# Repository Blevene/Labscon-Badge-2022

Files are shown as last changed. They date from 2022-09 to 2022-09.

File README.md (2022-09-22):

# Labscon-Badge-2022

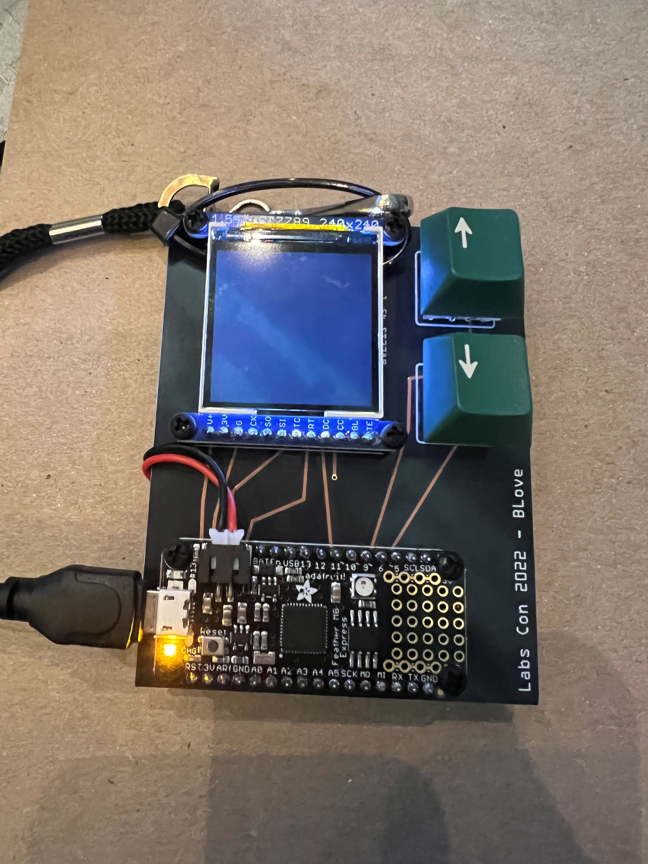
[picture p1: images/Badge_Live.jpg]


## Must use INDEXED bmp files to render on the TFT!

Good tutorial here (though it goes into a bunch of other stuff we don't care about): https://learn.adafruit.com/creating-your-first-tilemap-game-with-circuitpython/indexed-bmp-graphics

## You must add a CircuitPython bootloader to your AdaFruit Feather

## Instructions
Make sure to rename the .py file to code.py or main.py 

You can use most AdaFruit Feather form factor micro-controllers but M0 Express is probably the MINIMUM. 

On your CIRCUITPY drive you need the following folders

1) lib -> this contains third party libraries required to make things work (if you use a non-express board from Adafruit, you may need more libs in this folder)
2) bmp -> this is where your INDEXED bmp files live :-) Use GIMP to convert files to Indexed BMP format. NOTE: The screen is only 240 x 240
3) root folder of the drive should have "code.py"

### Parts used:

1) Adafruit Feather M0 Express - ATSAMD21 Cortex M0: https://www.adafruit.com/product/3403
2) Adafruit 1.54" 240x240 Wide Angle TFT LCD Display with MicroSD - ST7789: https://www.adafruit.com/product/3787
3) Kalih Box Crystal Navy Switches: https://kbdfans.com/products/kailh-box-crystal-navy-clicky-switches
4) PCB all files needed are located here https://github.com/Blevene/Labscon-Badge-2022/tree/main/LabsCon2022badge_V2
5) Nylon M2.5 Standoffs

Optional Parts:

1) LiPoly Battery - https://www.adafruit.com/product/1578 -> I used doublesided tape to secure this to the back of the PCB.
2) Tactile On/Off Switch w/Leads - https://www.adafruit.com/product/1092 -> Solder this to EN + Ground Pins on the back of the PCB after soldering the Feather on and you have on/off capabilities!

### Additional non-builtin Libraries Used: 

(these must be in the lib folder on the mounted CIRCUITPYTHON drive)

- adafruit_debouncer
- adafruit_ticks
- adafruit_st7789

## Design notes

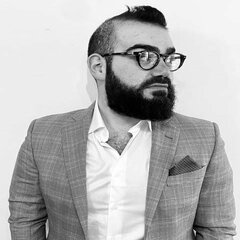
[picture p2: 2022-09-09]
images/jags_cwc_240x240.jpg

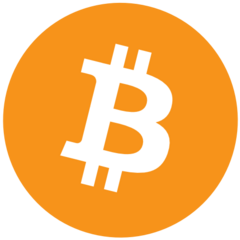
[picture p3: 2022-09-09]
images/bitcoin_240x240.png

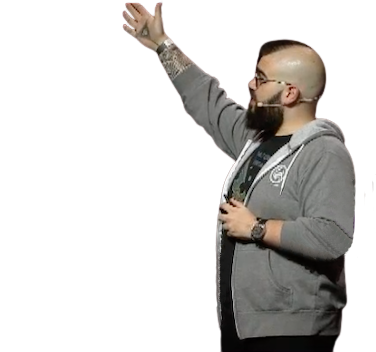
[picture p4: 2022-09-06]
images/behold-my-field-of-fucks_lb.png

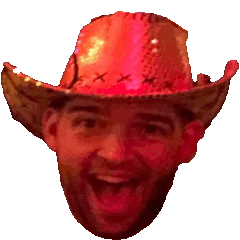
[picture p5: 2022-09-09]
bmp/bart.bmp

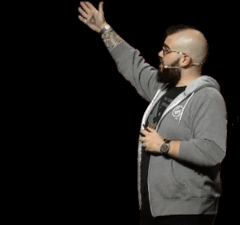
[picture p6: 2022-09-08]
bmp/jags_field.bmp

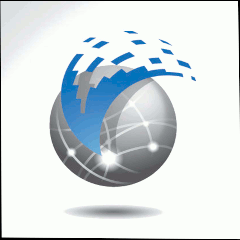
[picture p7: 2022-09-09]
bmp/mstic.bmp

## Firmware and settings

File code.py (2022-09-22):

import board
import os
import displayio
from digitalio import DigitalInOut, Direction, Pull
from adafruit_st7789 import ST7789
from adafruit_debouncer import Debouncer
import gc
import analogio

#On Startup, print Vbat Voltage to Serial
'''
 LiPoly batteries are 'maxed out' at 4.2V and stick around 3.7V for much of the battery life, 
 then slowly sink down to 3.2V or so before the protection circuitry cuts it off.
 Courtesy of AdaFruit - https://learn.adafruit.com/adafruit-feather-m0-express-designed-for-circuit-python-circuitpython/power-management
'''
vbat_voltage = analogio.AnalogIn(board.D9)

def get_voltage(pin):
    return (pin.value * 3.3) / 65536 * 2

battery_voltage = get_voltage(vbat_voltage)
print("VBat voltage: {:.2f}".format(battery_voltage))


# Initialize Switches!
switchL = DigitalInOut(board.D6)
switchL.direction = Direction.INPUT
switchL.pull = Pull.UP
switchL_d = Debouncer(switchL)

switchR = DigitalInOut(board.D5)
switchR.direction = Direction.INPUT
switchR.pull = Pull.UP
switchR_d = Debouncer(switchR)

# memory is kind of at a premium so lets make sure its not FUBAR
gc.collect()

spi = board.SPI()

# Release any resources currently in use for the displays
displayio.release_displays()

# Assign the relevant pins for our display
tft_cs = board.A4
tft_dc = board.D11

# instantiate the display bus over FourWire SPI
display_bus = displayio.FourWire(
    spi, command=tft_dc, chip_select=tft_cs, reset=board.D10
)

# instantiate the display object itself

display = ST7789(display_bus, width=240, height=240, rowstart=80)
#why does this make things so SLOW???
#display.rotation = 270

# supply the select_image var
def display_bitmap(image_index):
    while logo_group:
        logo_group.pop()
    bmp_select = f"bmp/{image_index}"
    print(bmp_select)
    bmp = displayio.OnDiskBitmap(bmp_select)
    tile_grid = displayio.TileGrid(bmp, pixel_shader=bmp.pixel_shader)
    logo_group.append(tile_grid)

# Create a Group to hold the Logo
logo_group = displayio.Group()

# Add the TileGrid to the Group
#logo_group.append(tile_grid)

# Add the Group to the Display
display.show(logo_group)
# --------------------------------------------------------
# Get a list of files in /bmp directory
path = "/bmp"
bmp_list = os.listdir(path)
print(bmp_list)
max_size = len(bmp_list) - 1
print(max_size)

# write a function to push
def shift_image(counter):
    return bmp_list[counter]


# initialize our variable to hold button press states
btn_value = 0
state_change = False

# Loop Forever
while True:
    # check the state of both switches
    switchL_d.update()
    switchR_d.update()

    if switchL_d.fell:
        btn_value -= 1
        state_change = True

    if switchR_d.fell:
        btn_value += 1
        state_change = True

    if btn_value > max_size or btn_value < -max_size:
        btn_value = 0

    if state_change == True:
        state_change = False  # reset the state change
        select_image = shift_image(btn_value)
        print(select_image)
        display_bitmap(select_image)

    # make sure we dont go above the length of our list
    # we also will let the buttons scroll around
    # if btn_value > (len(bmp_list) - 1) or btn_value < -1:
    #    btn_value = 0

    # select_image = shift_image(btn_value)
    # print(select_image)

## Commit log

2022-09-05 Adding sample initial graphics and code
2022-09-08 made sure JAGS image is small enough and added switch init code
2022-09-09 Added Push Button scrolling through bitmap images
2022-09-09 Updated Project Files
    Added Fritzing + PCB Files (gerbers) and a new image that was edited for BMP display.
    [CustomBadge_LabsCon_V2.fzz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]
2022-09-09 added comments
    added comments and omitted some debug console printing
2022-09-22 Add voltage state output to startup routine
2022-09-22 renamed main python script
    Match the expected CircuitPython nomenclature.
